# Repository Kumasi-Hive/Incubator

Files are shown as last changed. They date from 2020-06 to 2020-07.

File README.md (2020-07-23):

# Incubator

Microorganisms growth are influenced by several factors including temperature. The type of microorganism you are growing requires that you use the right temperature to achieve optimal growth. Microorganisms like fungi grow best at 25 degree celcius. On the other hand, bacteria, depending on which type you are growing will also require it's unique growing conditions and temperature. Escherichia coli, a model bacteria used for several life sciences experiment grows best at 37 degree celcius. Incubators are temperature controled chambers for growing microorganisms. However, incubators are often very expensive to buy in resource limited labs due to their expensive nature. Our goal on this project is to build a viarable temperature incubator using DIY methods and equipment and making it very easy for DIY Bio or community labs that are resource constraint to equally build their own incubator.  

## HARDWARE

1. Arduino Uno
2. Knob Potentiometer
3. 75W incandescent bulb
4. Push button
5. 16x2 LCD screen
6. 1 channel relay
7. Laser cutter

## SOFTWARE

1. Fritzing
2. Arduino IDE

## ALTERNATIVE HARDWARE

1. Replace sliding potentiometer with knob potentiometer
2. Replace 75W incandescent bulb with peltier element

## Acknowledgement

1. Andre Chagas \([Building Free Open Science Hardware](https://github.com/FOSH-following-demand)\)
2. Mboa Lab team \(Thomas Mboa, Lenshina and Stephane\([https://github.com/FOSH-following-demand/Incubator](https://github.com/FOSH-following-demand/Incubator) \)
3. OngolaFablab team
4. Open Bioeconomy Lab team
5. Kumasi Hive Makerspace Team

## References

[https://github.com/FOSH-following-demand](https://github.com/FOSH-following-demand)

[https://github.com/FOSH-following-demand/Incubator](https://github.com/FOSH-following-demand/Incubator)

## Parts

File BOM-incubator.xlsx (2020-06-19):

BILL OF MATERIAL |  |  | 907994.8943
HARDWARE | UNIT COST (USD) | QUANTITY | SUBTOTAL(USD) | LINK | CATALOG NO.
Arduino Uno | 12.08 | 1 | 12.08 | https://www.inventelectronics.com/product/arduino-uno-r3/ | DEV-001
Potentiometer | 1.22 | 1 | 1.22 | Any local hardware shop
Incandescent bulb (75W) | 5.18 | 1 | 5.18 | Available at local markets
Push button | 0.08 | 1 | 0.08 | Any local hardware shop
LCD Screen(16x2) | 3.4752 | 1 | 3.4752 | https://geekelectronics.io/shop/16x2-lcd-iic-blue-screen/ | GE0000001
One channel relay | 1.04 | 1 | 1.04 | https://geekelectronics.io/shop/30a-12v-relay/ | GE0000059
Cooler box | 43.17 | 1 | 43.17 | Available at local markets
 |  | TOTAL | 66.2452

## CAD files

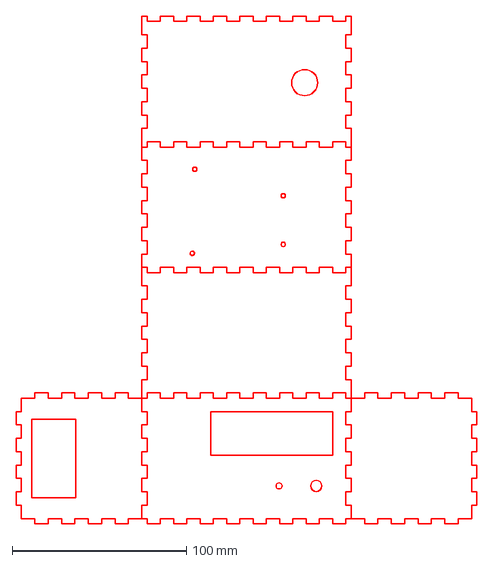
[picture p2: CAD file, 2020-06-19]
biolab_incubator/Laser cut parts/Incubator.dxf
264.0 x 291.0 mm

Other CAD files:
biolab_incubator/Laser cut parts/Incubator.dwg

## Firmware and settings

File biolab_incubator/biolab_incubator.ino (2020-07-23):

// The heat source is active low

#include <Wire.h> 
#include <LiquidCrystal_I2C.h>
// #include <OneWire.h>
// #include <DallasTemperature.h>
// #define ONE_WIRE_BUS 2

// OneWire oneWire(ONE_WIRE_BUS);
// DallasTemperature sensors(&oneWire);
#include "DHT.h"

#define DHTPIN 2 
#define DHTTYPE DHT11
DHT dht(DHTPIN, DHTTYPE);
LiquidCrystal_I2C lcd(0x38, 16, 2);

int startButton = 8;
int buttonState;
int heatPin = 9;
double temp_value = 0;
int pot = A0;
int pot_value;
double curTemp;
double prevTemp;
double max_temp = 0;


double set_pot() {
  pot_value = analogRead(pot);
  double max_value = map(pot_value, 0, 1023, 0, 100); //This is the desired temperature value
  return max_value;
}

long convert_time(long millisec) {
  int seconds = millisec/1000;
  if (seconds < 60) {
    lcd.print(seconds);
    lcd.print("secs");
  } else if (seconds >= 60) {
    int minutes = seconds/60;
    lcd.print(minutes);
    lcd.print("mins");
  }
}


boolean heatUp(double desired_temp) {
  unsigned long startTime = millis();
  // sensors.requestTemperatures();
  curTemp = dht.readTemperature();
  // Serial.print(curTemp);
  lcd.setCursor(0,1);
  lcd.print("Temp: ");
  lcd.print(curTemp);
  lcd.print((char)223);
  lcd.print("C");
  while (curTemp < desired_temp) {
    int pulseDuration = min(10000,20000);
    digitalWrite(heatPin,LOW);
    delay(pulseDuration);
    digitalWrite(heatPin,HIGH);

    // check if temperatue is equal to or more than desired temperature
    curTemp = dht.readTemperature();
    // Serial.print(curTemp);
    lcd.setCursor(0,1);
    lcd.print("Temp: ");
    lcd.print(curTemp);
    lcd.print((char)223);
    lcd.print("C");
    if (curTemp >= desired_temp)
    break;

    // Wait a little as we approach desired temperature to avoid overheating
    if ((desired_temp - curTemp) < 2){
      do {
        prevTemp = curTemp;
        delay(1000);
        curTemp = dht.readTemperature();
        lcd.setCursor(0,1);
        lcd.print("Temp: ");
        lcd.print(curTemp);
        lcd.print((char)223);
        lcd.print("C");
        // Serial.print(curTemp);
      } while(curTemp > prevTemp);
    }

    // check if temperature is equal to or more than desired temperature
    if (curTemp >= desired_temp)
    break;
  }
  return true;
}

void holdConstantTemp(double idealTemp) {
  while (true) {
    lcd.setCursor(0,1);
    lcd.print(idealTemp);
    lcd.print((char)223);
    lcd.print("C");
    curTemp = dht.readTemperature();
    Serial.print(curTemp);
    if (curTemp < idealTemp) {
      digitalWrite(heatPin,HIGH);
      delay(5000);
      digitalWrite(heatPin,LOW);
    } else if (curTemp > (idealTemp+0.5)) {
      digitalWrite(heatPin,HIGH); //Turning off source of heat so it cools down naturally
    }
    delay(2000);
  }
}

void runIncubator() {
  lcd.clear();
  delay(1000);
  lcd.setCursor(0,0);
  lcd.print("Set Temp:");
  while (true) {
    lcd.setCursor(9,0);
    temp_value = set_pot();
    lcd.print(temp_value);
    lcd.print((char)223);
    lcd.print("C");
    // Serial.println(temp_value);
    // Serial.println("deg Celcius");
    buttonState = digitalRead(startButton);
    if (buttonState == LOW) {
      break;
    }
    delay(1000);
   }
  unsigned long startTime = millis();
  delay(1000);
  lcd.clear();
  lcd.setCursor(0,0);
  lcd.print("HEATING UP");
  if (!heatUp(temp_value)) {
    lcd.clear();
    lcd.setCursor(0,0);
    lcd.print("Heat can't raise");
    lcd.setCursor(0,1);
    lcd.print("Something wrong");
  } else {
    //do nothing;
  }
  long timeElapsed = millis() - startTime;
  lcd.clear();
  lcd.setCursor(0,0);
  lcd.print("Total heat time");
  lcd.setCursor(0,1);
  lcd.print(convert_time(timeElapsed));
  // Serial.println();
  delay(2000);
  lcd.clear();
  lcd.setCursor(0,0);
  lcd.print("Holding temp");
    
  max_temp = temp_value;
  holdConstantTemp(max_temp);
}


void setup() {
  Serial.begin(9600);
  dht.begin();
  lcd.begin();
  lcd.backlight();
  pinMode(startButton,INPUT);
  pinMode(heatPin,OUTPUT);
  digitalWrite(startButton,HIGH);
  digitalWrite(heatPin,HIGH);
  lcd.setCursor(0,0);
  lcd.print("Starting in ");
  delay(1000);
  for (int i = 5; i > 0; i--) {
    lcd.setCursor(13,0);
    lcd.print(i);
    lcd.print("..");
    delay(1000);
  }
  runIncubator();
}

void loop() {
  // put your main code here, to run repeatedly:

}

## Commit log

2020-06-19 initial commits
    [BOM-incubator.xlsx, Incubator.dwg, Incubator.dxf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]
2020-06-20 clarification on signals
    Clarifying why the signals look reversed. The signals used to turn on the heat source which is controlled by a relay is both active low.
    [biolab_incubator.ino]
2020-07-23 updated convert_time function
    Corrected the time calculation in the convert_time function
    [biolab_incubator.ino]
